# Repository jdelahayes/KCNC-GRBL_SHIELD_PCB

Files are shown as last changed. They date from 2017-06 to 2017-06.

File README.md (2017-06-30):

KCNC GRBL SHIELD 

Ceci est un shield GRBL pour Arduino Uno adapté à la R-CNC (makerfr.com).

TODO
Elargir les pads à 2.54mm pour permettre l'utilisation de rivets de 1.4mm (la tete mesure dans ce cas 2.35mm) sur :
 - les borniers à vis 2 et 3 points;
 - le regulateur 7805
 - les condensateurs polarisés

Nettoyer les angles des pistes.

Réduire le longeur de la carte pour avoir une marge sur les plaque présensibilisées au format 160x100mm

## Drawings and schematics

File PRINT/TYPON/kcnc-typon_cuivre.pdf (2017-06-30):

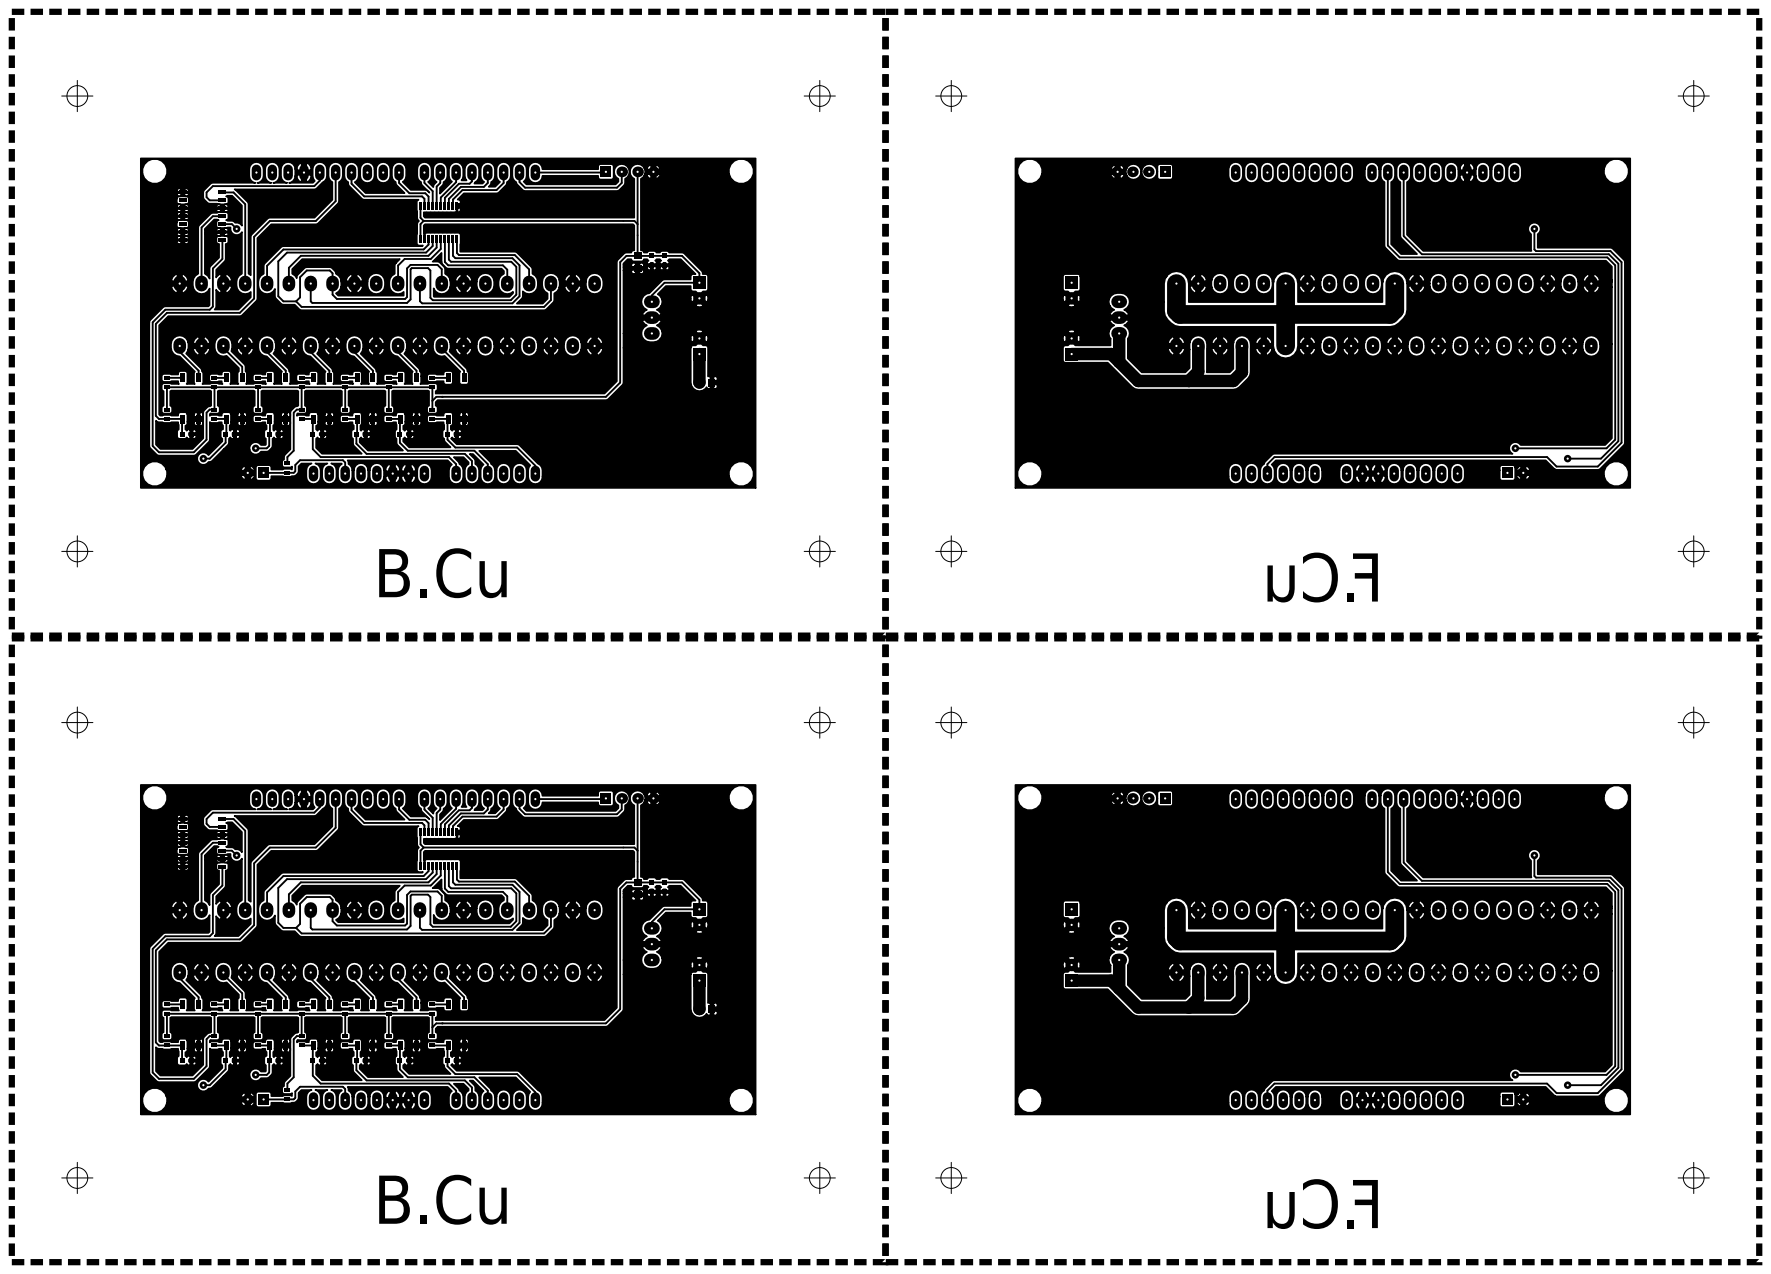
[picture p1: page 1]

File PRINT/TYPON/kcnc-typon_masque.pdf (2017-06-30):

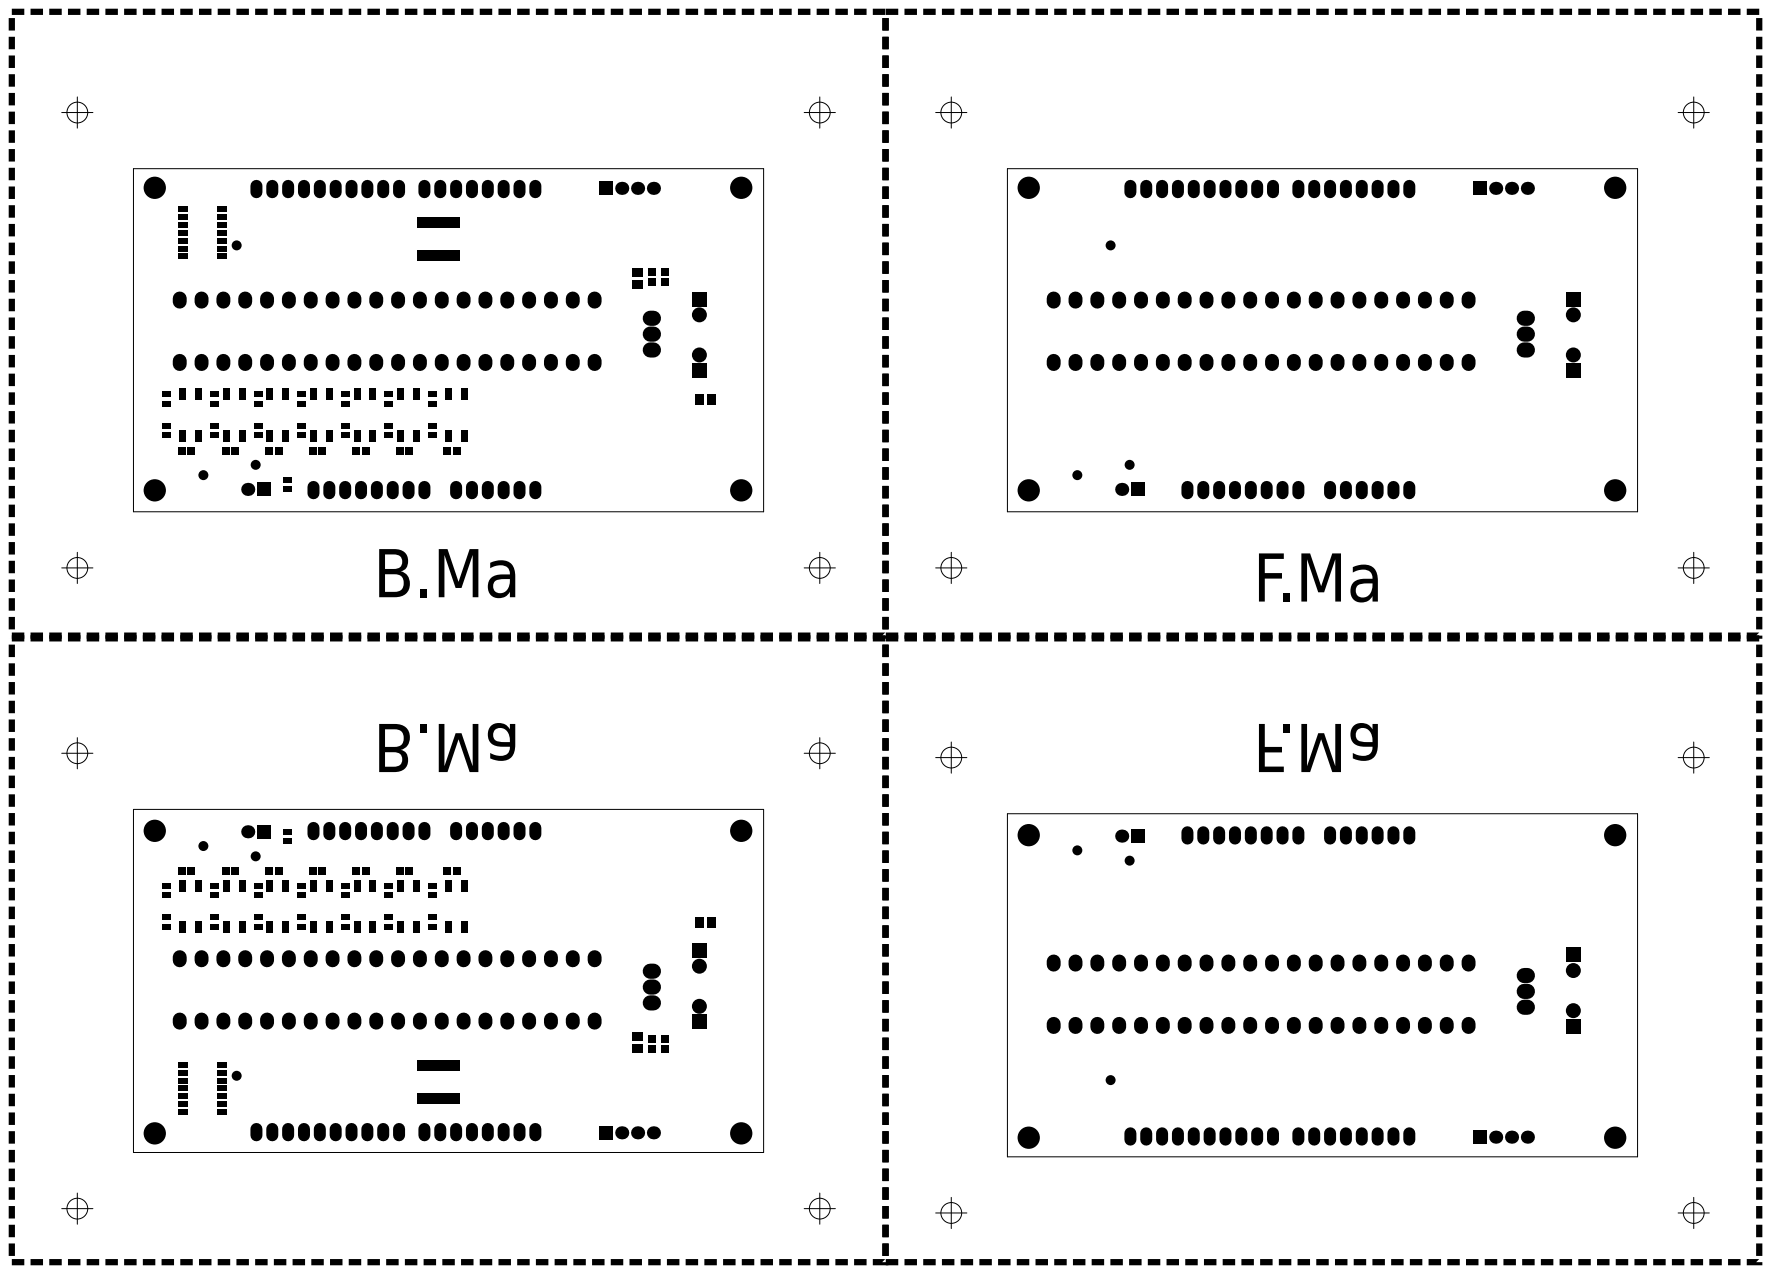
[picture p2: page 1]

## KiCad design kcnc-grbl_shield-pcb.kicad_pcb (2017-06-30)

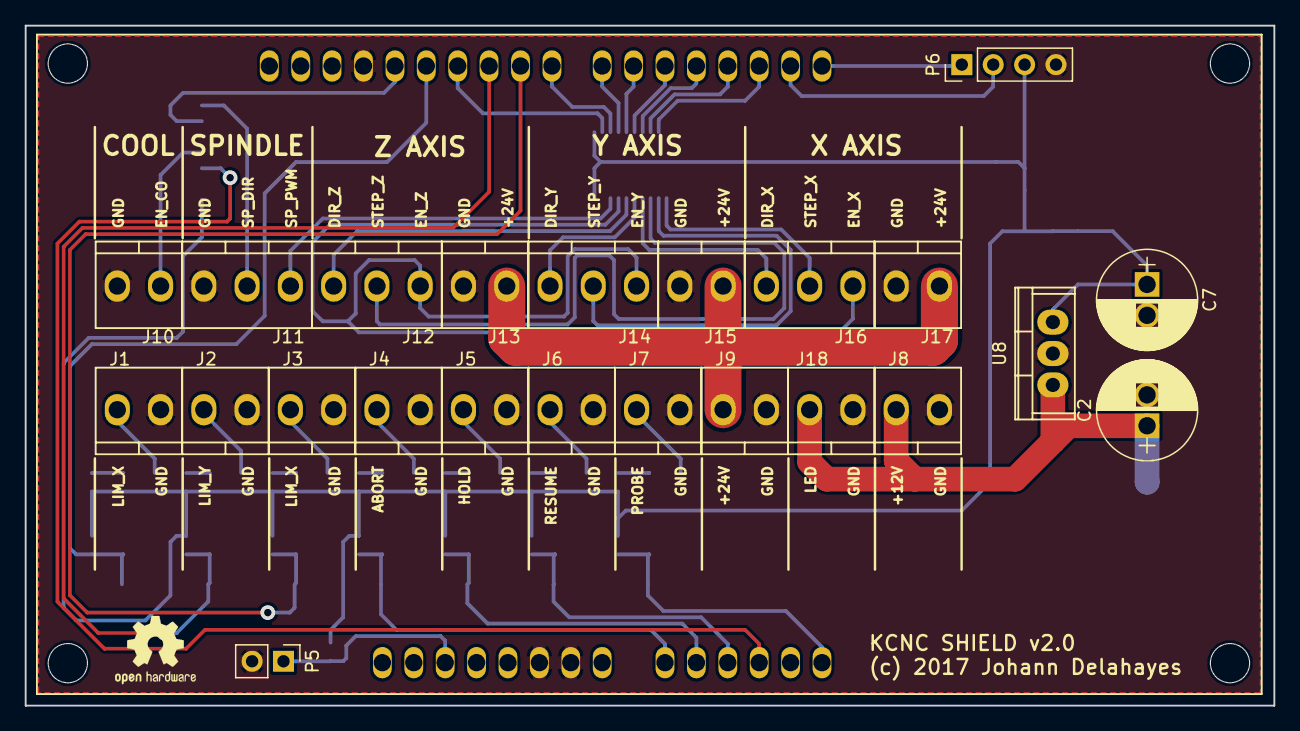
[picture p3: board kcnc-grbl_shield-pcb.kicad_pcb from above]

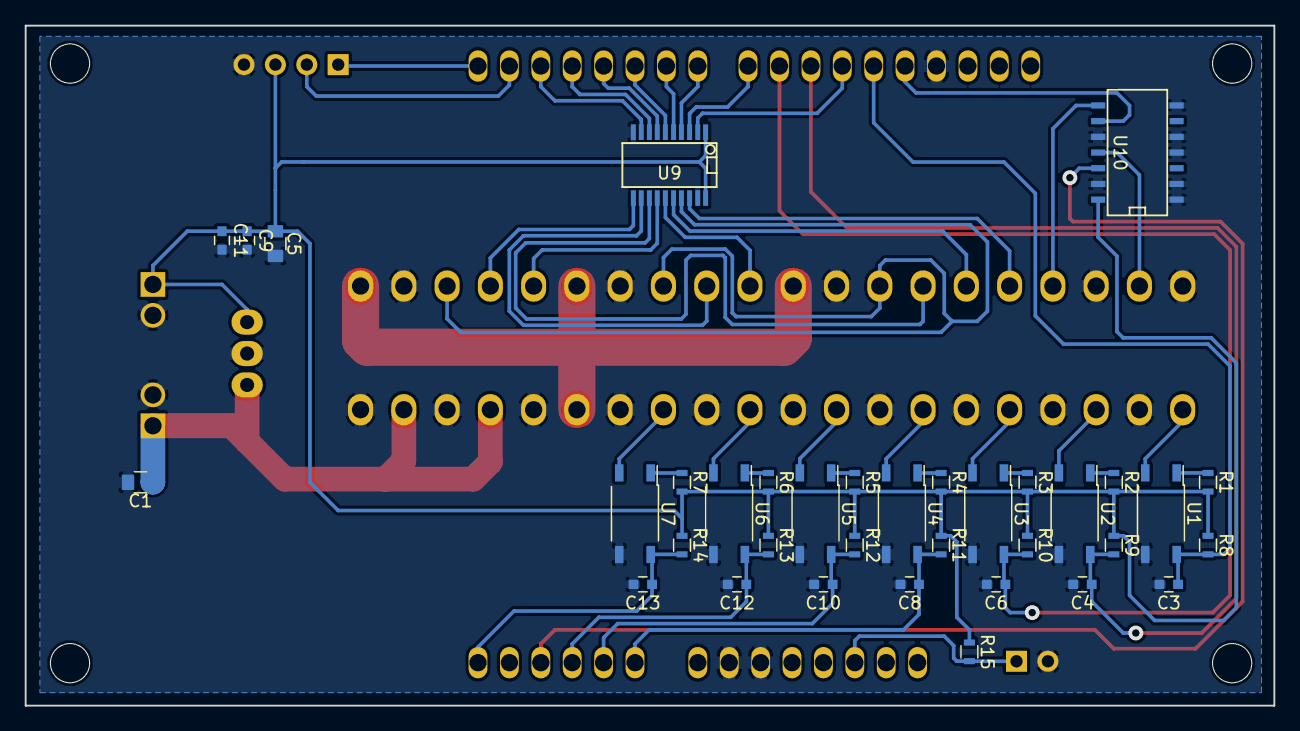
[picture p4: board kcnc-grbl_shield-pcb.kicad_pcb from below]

Board: 2 copper layers, 101.0 x 55.0 mm, 59 parts (35 on the bottom side), 48 nets.

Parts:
C1, C5: 1µF; C_0805
C2, C7: 470µF; CP_Radial_D8.0mm_P2.50mm
C3, C4, C6, C8, C10, C12, C13: 100nF; C_0603
C9, C11: 1µF; C_0603
J1: limZ; screw_terminal_3.5mm_pitch_2p
J2: limY; screw_terminal_3.5mm_pitch_2p
J3: limX; screw_terminal_3.5mm_pitch_2p
J4: abort; screw_terminal_3.5mm_pitch_2p
J5: hold; screw_terminal_3.5mm_pitch_2p
J6: resume; screw_terminal_3.5mm_pitch_2p
J7: probe; screw_terminal_3.5mm_pitch_2p
J8: +12V; screw_terminal_3.5mm_pitch_2p
J9: +24V; screw_terminal_3.5mm_pitch_2p
J10: COOLANT; screw_terminal_3.5mm_pitch_2p
J11: SPINDLE; screw_terminal_3.5mm_pitch_3p
J12: Z_CTRL; screw_terminal_3.5mm_pitch_3p
J13: Z_ALIM; screw_terminal_3.5mm_pitch_2p
J14: Y_CTRL; screw_terminal_3.5mm_pitch_3p
J15: Y_ALIM; screw_terminal_3.5mm_pitch_2p
J16: X_CTRL; screw_terminal_3.5mm_pitch_3p
J17: X_ALIM; screw_terminal_3.5mm_pitch_2p
J18: LED; screw_terminal_3.5mm_pitch_2p
P5: RESET; Pin_Header_Straight_1x02_Pitch2.54mm
P6: RS232; Pin_Header_Straight_1x04_Pitch2.54mm
R1, R2, R3, R4, R5, R6, R7: 1k; R_0603
R8, R9, R10, R11, R12, R13, R14, R15: 10k; R_0603
SHIELD1: ARDUINO_UNO_REV3_SHIELD; KCNC_GRBL_SHIELD
U1, U2, U3, U4, U5, U6, U7: TLP185; Toshiba_SOP_Pins1346_4.4x3.6mm_Pitch1.27mm
U8: LM7805CT; TO-220
U9: 74HCT245P; SSOP-20
U10: 74HC125AN; SOIC-14_N

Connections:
+5V: C5.1, C7.1, C9.1, C11.1, P6.3, R1.2, R2.2, R3.2, R4.2, R5.2, R6.2, R7.2, R8.1, R9.1, R10.1, R11.1, R12.1, R13.1, R14.1, R15.1, U8.3, U9.1, U9.20, U10.14
+12V: C1.1, C2.1, J8.1, J18.1, U8.1
+24V: J9.1, J13.1, J15.1, J17.1
GND: C1.2, C2.2, C3.2, C4.2, C5.2, C6.2, C7.2, C8.2, C9.2, C10.2, C11.2, C12.2, C13.2, J1.2, J2.2, J3.2, J4.2, J5.2, J6.2, J7.2, J8.2, J9.2, J10.2, J11.3, J13.2, J15.2, J17.2, J18.2, P5.2, P6.4, SHIELD1.GND1, SHIELD1.GND2, SHIELD1.GND3, U1.4, U2.4, U3.4, U4.4, U5.4, U6.4, U7.4, U8.2, U9.10, U9.19, U10.1, U10.2, U10.4, U10.5, U10.7, U10.10, U10.13
unnamed: J1.1, U1.3
unnamed: J2.1, U2.3
unnamed: J3.1, U3.3
unnamed: J4.1, U4.3
unnamed: J5.1, U5.3
unnamed: J6.1, U6.3
unnamed: J7.1, U7.3
unnamed: R1.1, U1.1
unnamed: R2.1, U2.1
unnamed: R3.1, U3.1
unnamed: R4.1, U4.1
unnamed: R5.1, U5.1
unnamed: R6.1, U6.1
unnamed: R7.1, U7.1
RST: P5.1, R15.2, SHIELD1.RST
RX: P6.1, SHIELD1.0
TX: P6.2, SHIELD1.1
b_out_COOLANT: J10.1, U10.11
b_out_DIR_X: J16.3, U9.14
b_out_DIR_Y: J14.3, U9.15
b_out_DIR_Z: J12.3, U9.16
b_out_ENABLE: J12.1, J14.1, J16.1, U9.17
b_out_SPINDLE_DIR: J11.2, U10.8
b_out_SPINDLE_PWM: J11.1, U9.18
b_out_STEP_X: J16.2, U9.11
b_out_STEP_Y: J14.2, U9.12
b_out_STEP_Z: J12.2, U9.13
in_ABORT: C8.1, R11.2, SHIELD1.AD0, U4.6
in_HOLD: C10.1, R12.2, SHIELD1.AD1, U5.6
in_LIMIT_X: C6.1, R10.2, SHIELD1.9, U3.6
in_LIMIT_Y: C4.1, R9.2, SHIELD1.10, U2.6
in_LIMIT_Z: C3.1, R8.2, SHIELD1.12, U1.6
in_PROBE: C13.1, R14.2, SHIELD1.AD5, U7.6
in_RESUME: C12.1, R13.2, SHIELD1.AD2, U6.6
out_COOLANT: SHIELD1.AD3, U10.12
out_DIR_X: SHIELD1.5, U9.6
out_DIR_Y: SHIELD1.6, U9.5
out_DIR_Z: SHIELD1.7, U9.4
out_ENABLE: SHIELD1.8, U9.3
out_SPINDLE_DIR: SHIELD1.13, U10.9
out_SPINDLE_PWM: SHIELD1.11, U9.2
out_STEP_X: SHIELD1.2, U9.9
out_STEP_Y: SHIELD1.3, U9.8
out_STEP_Z: SHIELD1.4, U9.7

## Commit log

2017-05-24 Init arduino uno grbl shield
    [arduino_uno_grbl_shield.kicad_pcb, arduino_uno_grbl_shield.sch]
2017-06-14 Schema v0.1
    [arduino_uno_grbl_shield.sch]
2017-06-16 Commit V1.0
    [ArduinoUno.dxf, arduino_uno_grbl_shield.csv, arduino_uno_grbl_shield.kicad_pcb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]
2017-06-30 Version 2
    Commit de la version 2
    [ArduinoUno.dxf, arduino_uno_grbl_shield.csv, arduino_uno_grbl_shield.kicad_pcb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]

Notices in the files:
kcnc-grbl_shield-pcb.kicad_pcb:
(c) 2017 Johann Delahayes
